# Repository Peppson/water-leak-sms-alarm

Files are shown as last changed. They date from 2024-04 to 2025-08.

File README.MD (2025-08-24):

# water-leak-sms-alarm   
A small battery-powered device that detects water leakage and sends an SMS alert.  
&nbsp;
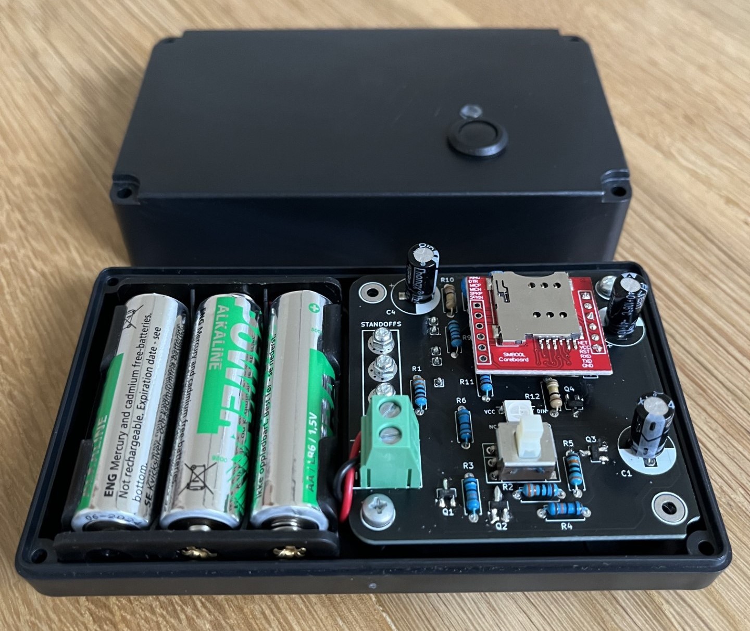
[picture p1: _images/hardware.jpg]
Hardware


&nbsp; 
## Features
- Completely `off` until water *(or anything conductive)* closes the circuit between two of its legs,  
thereby latching on the "soft latching power circuit".  
Which can later be turned off again by the microcontroller.

- Latches `on` by either water detection or by pressing the test button.

- Sends an SMS alert if water is detected.

- Sends SMS diagnostics if the test button is pressed.

- Built with an ESP32 and PlatformIO, in C++.

&nbsp; 
## Schematic and PCB
KiCad files can be found here: 
[📂 _KiCad/](./_KiCad/)  
More images in: 
[📂 _images/](./_images/)
<details>
    <summary>
        Parts used
    </summary>   

- ESP32 D1 Mini Node MCU 
- SIM800L module with external antenna  
- 3.3V LDO: MCP1700-3302E (250mA)
- LED: WS2812B  
- P-channel mos: NTR4101PT1G 
- N-channel mos: PMV16XNR  
- Cap 470uF: Electrolytic  
- Cap 22uF: Electrolytic
- Cap 1uF: Ceramic  
- Cap 100nF: Ceramic
- Switch: Momentary DPST  
- Conductive legs in copper/brass  
</details>

<details>
    <summary>
        PCB
    </summary>   

> Uses mostly through-hole components for easier soldering.  
> ESP32 is mounted on the bottom side of the PCB.

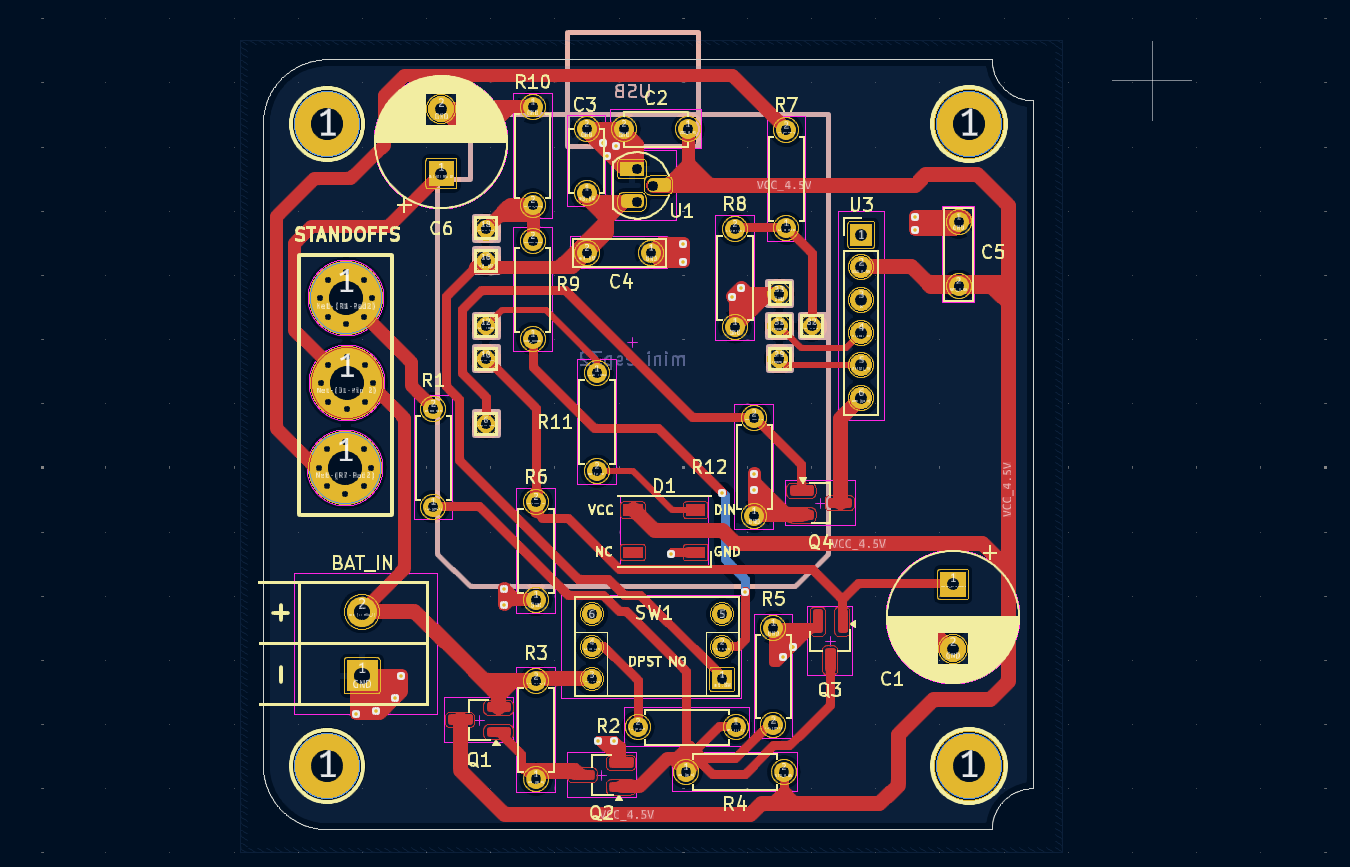
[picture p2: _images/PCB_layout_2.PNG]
PCB

&nbsp;
</details>

### Schematic
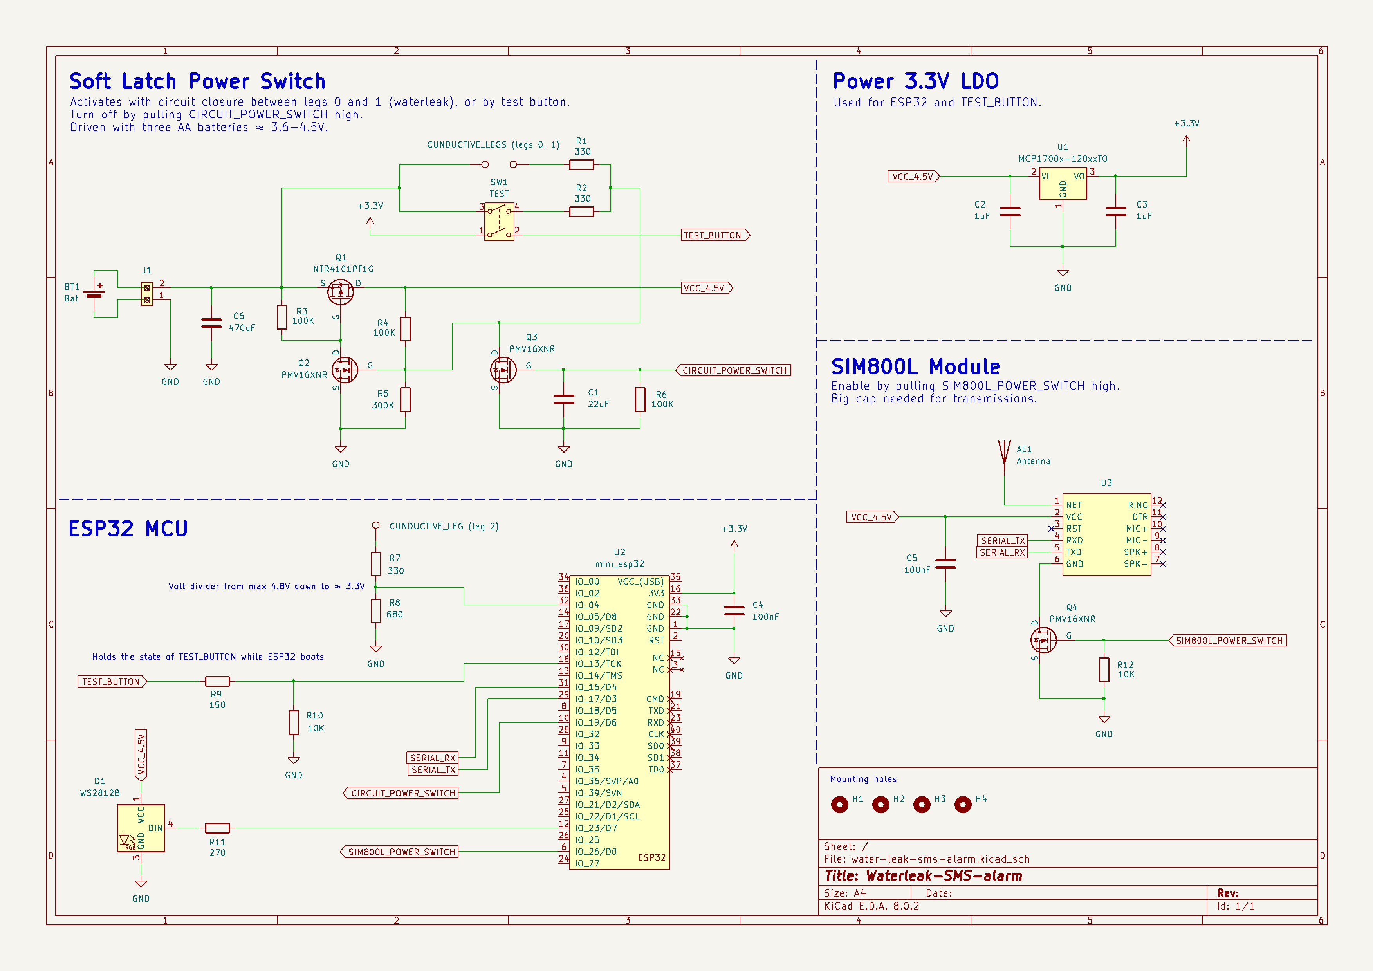
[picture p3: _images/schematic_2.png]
Schematic


### SMS Example

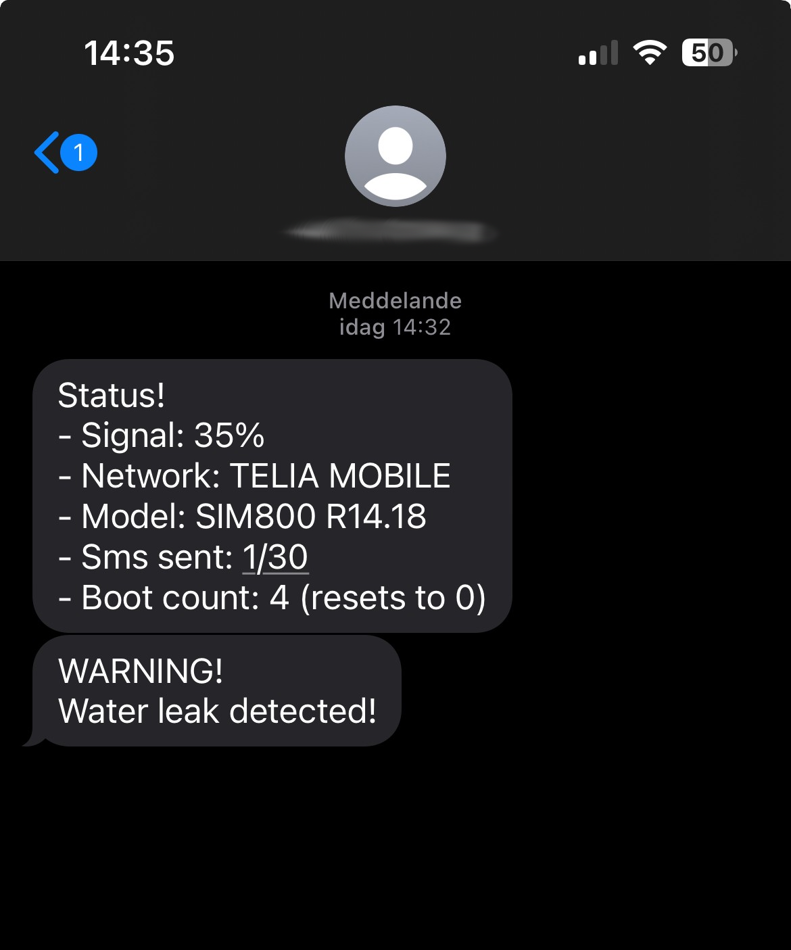
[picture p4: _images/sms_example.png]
SMS Example


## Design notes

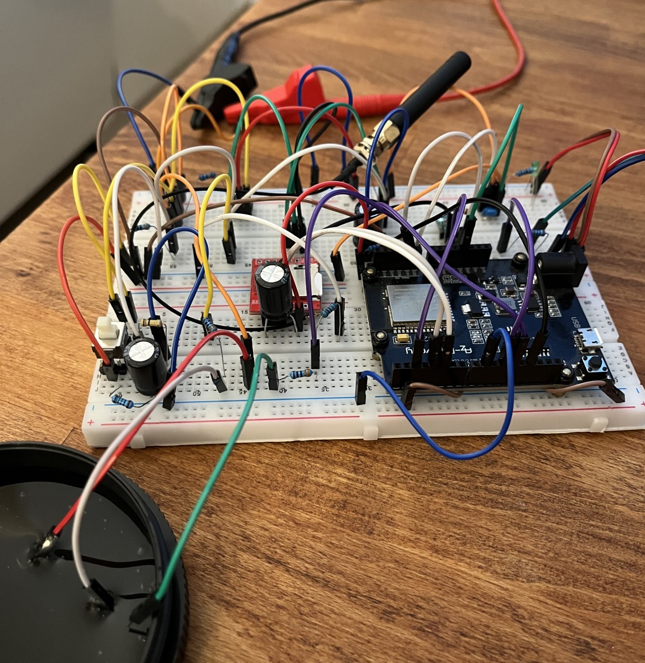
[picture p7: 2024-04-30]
_images/prototype.jpg

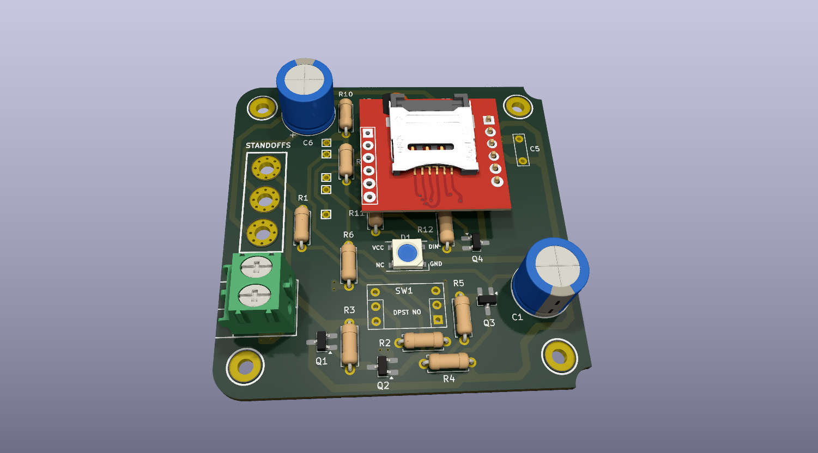
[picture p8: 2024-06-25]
_images/PCB_render_2.PNG

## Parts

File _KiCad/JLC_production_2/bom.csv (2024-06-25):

Designator | Footprint | Quantity | Value | LCSC Part #
BAT_IN | TerminalBlock_Philmore_TB132_1x02_P5.00mm_Horizontal | 1 | Screw_Terminal_01x02
C1 | CP_Radial_D10.0mm_P5.00mm | 1 | 470uF
C2, C3 | C_Disc_D4.7mm_W2.5mm_P5.00mm | 2 | 1uF
C4, C5 | C_Rect_L7.0mm_W2.0mm_P5.00mm | 2 | C_Rect_L7.0mm_W2.0mm_P5.00mm
C6 | CP_Radial_D10.0mm_P5.00mm | 1 | 470
D1 | LED_WS2812B_PLCC4_5.0x5.0mm_P3.2mm | 1 | WS2812B
Q1 | SOT-23_Handsoldering | 1 | NTR4101PT1G
Q2, Q3, Q4 | SOT-23_Handsoldering | 3 | PMV16XNR
R1, R2, R7 | R_Axial_DIN0207_L6.3mm_D2.5mm_P7.62mm_Horizontal | 3 | 330
R10, R12 | R_Axial_DIN0207_L6.3mm_D2.5mm_P7.62mm_Horizontal | 2 | 10K
R11 | R_Axial_DIN0207_L6.3mm_D2.5mm_P7.62mm_Horizontal | 1 | 270
R3, R4, R6 | R_Axial_DIN0207_L6.3mm_D2.5mm_P7.62mm_Horizontal | 3 | 100K
R5 | R_Axial_DIN0207_L6.3mm_D2.5mm_P7.62mm_Horizontal | 1 | 300K
R8 | R_Axial_DIN0207_L6.3mm_D2.5mm_P7.62mm_Horizontal | 1 | 680
R9 | R_Axial_DIN0207_L6.3mm_D2.5mm_P7.62mm_Horizontal | 1 | 150
S1 | MountingHole_2.7mm_M2.5_Pad_Via | 1 | CUNDUCTIVE_LEGS (legs 0, 1)
S2 | MountingHole_2.7mm_M2.5_Pad_Via | 1 | CUNDUCTIVE STANDOFFS (legs 1, 2)
S3 | MountingHole_2.7mm_M2.5_Pad_Via | 1 | CUNDUCTIVE_LEG (leg 2)
SW1 | SW_NKK_G1xJP | 1 | TEST
U1 | TO-92_HandSolder | 1 | MCP1700x-120xxTO
U2 | esp32-wemos-d1-mini | 1 | mini_esp32
U3 | PinHeader_1x06_P2.54mm_Vertical | 1 | SIM800L-CORE

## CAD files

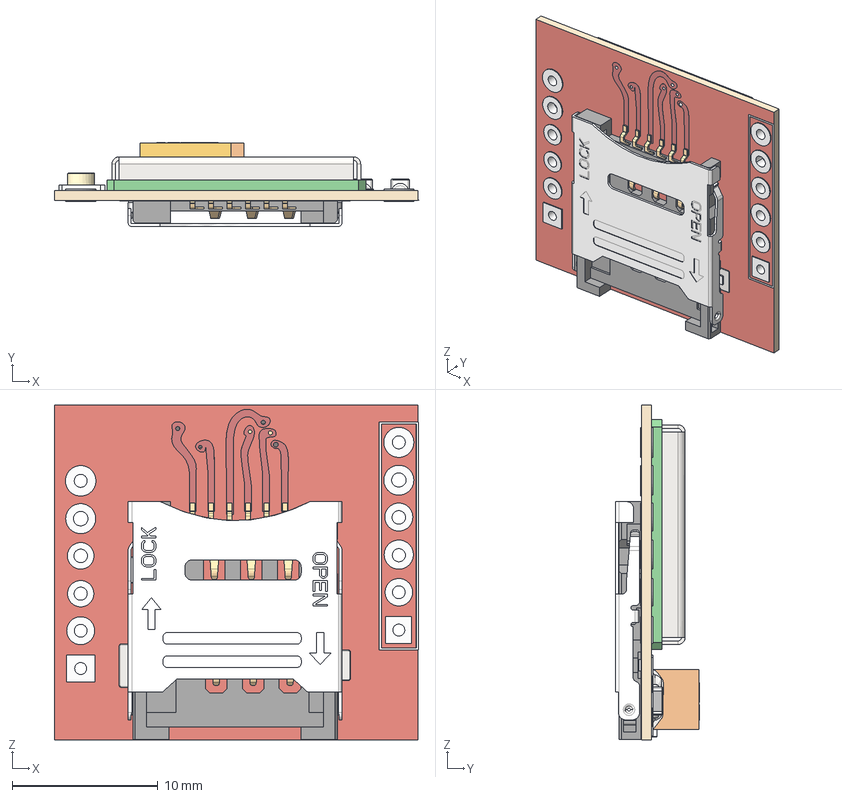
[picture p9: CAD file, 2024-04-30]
_KiCad/SIM800L-Core-Module-KiCad-Footprint-main/SIM800L v10.step
25.0 x 5.77 x 23.0 mm
PCB
Cage
CH03-HB

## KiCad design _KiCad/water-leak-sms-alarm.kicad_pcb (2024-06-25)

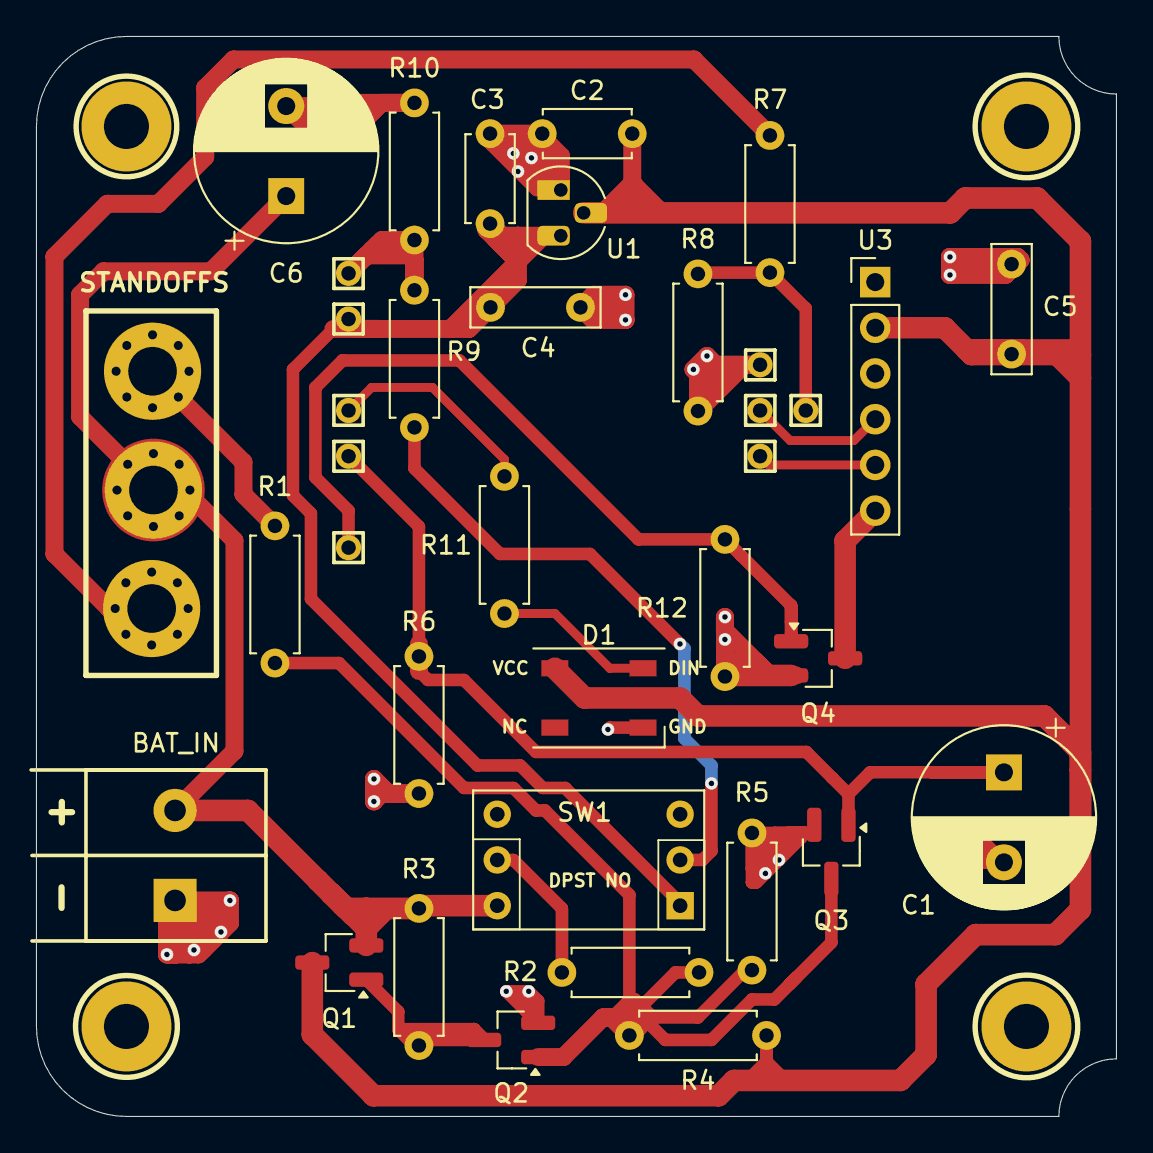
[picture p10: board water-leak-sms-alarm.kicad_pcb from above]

Board: 2 copper layers, 60.0 x 60.0 mm, 35 parts (1 on the bottom side), 19 nets.

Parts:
BAT_IN: Screw_Terminal_01x02; TerminalBlock_Philmore_TB132_1x02_P5.00mm_Horizontal
C1: 470uF; CP_Radial_D10.0mm_P5.00mm
C2, C3: 1uF; C_Disc_D4.7mm_W2.5mm_P5.00mm
C4, C5: C_Rect_L7.0mm_W2.0mm_P5.00mm
C6: 470; CP_Radial_D10.0mm_P5.00mm
D1: WS2812B; LED_WS2812B_PLCC4_5.0x5.0mm_P3.2mm
H1, H2, H3, H4: MountingHole; MountingHole_2.5mm_Pad
Q1: NTR4101PT1G; SOT-23_Handsoldering
Q2, Q3, Q4: PMV16XNR; SOT-23_Handsoldering
R1, R2, R7: 330; R_Axial_DIN0207_L6.3mm_D2.5mm_P7.62mm_Horizontal
R3, R4, R6: 100K; R_Axial_DIN0207_L6.3mm_D2.5mm_P7.62mm_Horizontal
R5: 300K; R_Axial_DIN0207_L6.3mm_D2.5mm_P7.62mm_Horizontal
R8: 680; R_Axial_DIN0207_L6.3mm_D2.5mm_P7.62mm_Horizontal
R9: 150; R_Axial_DIN0207_L6.3mm_D2.5mm_P7.62mm_Horizontal
R10, R12: 10K; R_Axial_DIN0207_L6.3mm_D2.5mm_P7.62mm_Horizontal
R11: 270; R_Axial_DIN0207_L6.3mm_D2.5mm_P7.62mm_Horizontal
S1: CUNDUCTIVE_LEGS (legs 0, 1); MountingHole_2.7mm_M2.5_Pad_Via
S2: CUNDUCTIVE STANDOFFS (legs 1, 2); MountingHole_2.7mm_M2.5_Pad_Via
S3: CUNDUCTIVE_LEG (leg 2); MountingHole_2.7mm_M2.5_Pad_Via
SW1: TEST; SW_NKK_G1xJP
U1: MCP1700x-120xxTO; TO-92_HandSolder
U2: mini_esp32; esp32-wemos-d1-mini
U3: SIM800L-CORE; PinHeader_1x06_P2.54mm_Vertical

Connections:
+3.3V: C3.1, C4.2, SW1.1, U1.3 (VO), U2.16 (3V3)
CIRCUIT_POWER_SWITCH: C1.1, Q3.1 (D), R6.2, U2.10 (IO_19/D6)
GND: BAT_IN.1, C1.2, C2.2, C3.2, C4.1, C5.1, C6.2, D1.3 (GND), Q2.2 (G), Q3.2 (G), Q4.2 (G), R5.1, R6.1, R8.1, R10.1, R12.1, U1.1 (GND), U2.33 (GND)
unnamed: D1.4 (DIN), R11.2
unnamed: BAT_IN.2, C6.1, Q1.2 (G), R3.2, S1.1, SW1.3
unnamed: Q1.1 (D), Q2.3 (S), R3.1
unnamed: Q2.1 (D), Q3.3 (S), R1.1, R2.1, R4.1, R5.2
unnamed: Q4.3 (S), U3.6 (GND)
unnamed: R1.2, S2.1
unnamed: R2.2, SW1.4
unnamed: R7.2, S3.1
unnamed: R7.1, R8.2, U2.32 (IO_04)
unnamed: R9.2, R10.2, U2.18 (IO_13/TCK)
unnamed: R11.1, U2.12 (IO_23/D7)
SERIAL_RX: U2.29 (IO_17/D3), U3.5 (TXD)
SERIAL_TX: U2.31 (IO_16/D4), U3.4 (RXD)
SIM800L_POWER_SWITCH: Q4.1 (D), R12.2, U2.6 (IO_26/D0)
TEST_BUTTON: R9.1, SW1.2
VCC_4.5V: C2.1, C5.2, D1.1 (VCC), Q1.3 (S), R4.2, U1.2 (VI), U3.2 (VCC)

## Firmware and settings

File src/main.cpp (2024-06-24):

#include "config.h"
#include "core/gsm_module.h"
#include "core/hardware.h"
#include "core/memory.h"
#include "utility.h"

using namespace hardware;
Memory memory;
GsmModule sms;

// Main
void setup() {
    begin_hardware(&memory, &sms);

    // Diagnostic test button
    if (is_test_button_pressed()) {
        sms.send_message(SMSType::Diagnostic);
        system_shutdown();
    }

    // Did we wake up from deepsleep? (reboots itself after deepsleep)
    if (woke_up_from_deepsleep()) {
        system_shutdown();
    }

    // Normal boot
    memory.increment_eeprom_count(MemAddr::BootCount, 1, false);  

    if (is_water_leak_detected()) {
        sms.send_message(SMSType::Alert);
        deepsleep(DEEPSLEEP_DURATION_LONG);  // Deepsleep to prevent retriggering
        /*OFF*/
    } else {
        deepsleep(DEEPSLEEP_DURATION_SHORT);  // False positive
        /*OFF*/
    }

    // Debug/development
    #if USB_SERIAL_ENABLED && DEBUG_LOOP_ENABLED
        util::debug_loop(memory, sms);
    #endif
}


void loop() {
    system_shutdown(); // Should never get here
} 

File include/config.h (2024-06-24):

#pragma once
#include <Arduino.h>
#include <stdbool.h>
#include <stdexcept>
#include <stdio.h>
#include <string>
#include <EEPROM.h>


// Dev
#define SEND_SMS_ENABLED 1                                          // SMS toggle 
#define USB_SERIAL_ENABLED 0                                        // USB serial connection toggle
#define DEBUG_LOOP_ENABLED 0                                        // Enter debug loop
#define DEBUG_LOOP_PING 0                                           // Serial print (".") while in debug_loop, sometimes helps with connection     
#define RESET_ALL 0                                                 // Resets all counters and await new code upload   

// Setup
constexpr const char* SMS_ALERT_ROW_0 = "WARNING!";                 // Alert sms first row
constexpr const char* SMS_ALERT_ROW_1 = "Water leak detected!";     // Alert sms second row
constexpr const char* SMS_DIAGNOSTIC_ROW_0 = "Status!";             // Diagnostic sms first row
constexpr uint32_t CONNECTION_TIMEOUT = 45*1000;                    // Wait for GSM network connection (mS)
constexpr uint32_t DEEPSLEEP_DURATION_LONG = 2*60*60;               // Deepsleep after waterleak is detected (S)
constexpr uint32_t DEEPSLEEP_DURATION_SHORT = 10;                   // Deepsleep after false positive (S)
constexpr uint16_t SERIAL_RESPONSE_TIMEOUT = 75;                    // Wait for serial response from SIM800L (mS)
constexpr uint16_t MAX_SMS_UNTILL_EMPTY_SIMCARD = 50;               // How many sms can we send in total? (money/sms cost)
constexpr uint64_t DEEPSLEEP_uS_TO_S_FACTOR = 1000000;              // Factor

// Physical I/O
#define PIN_CIRCUIT_POWER_SWITCH 19                                 // Pull HIGH to turn off ALL power (latching circuit)
#define PIN_SIM800L_POWER_SWITCH 26                                 // Turn on/off power to the SIM800L module 
#define PIN_TEST_BUTTON 13                                          // Input push button
#define PIN_WATERLEAK_DETECT 4                                      // Input (third conductive leg) to detect water leakage
#define PIN_LED 23                                                  // Datapin WS2812B led (SPI MOSI)
#define PIN_SIM800L_RX 17                                           // ESP32 hardware serial 2 RX
#define PIN_SIM800L_TX 16                                           // ESP32 hardware serial 2 TX

// Print toggle
#if USB_SERIAL_ENABLED
    #define log(...) Serial.printf(__VA_ARGS__)
    #define STOP log("\n-----  Stop right there criminal scum!  ----- \n"); while (1) { delay(1); }
#else
    #define log(...)
    #define STOP
#endif

// Enums
enum class SMSType : uint8_t {
    Alert,
    Diagnostic,
    None
};

enum class Color : uint8_t {
    Orange,
    Green,
    Blue,
    Red,
    Off
};

enum MemAddr : int {
    BootCount,
    SmsSent,
    NumOfMemAddr  // Num of items. Well, it only grew to two
};

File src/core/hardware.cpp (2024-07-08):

#include "core/hardware.h"
#include "utility.h"
#include <HardwareSerial.h>

namespace hardware {
    
static NeoPixelBus<NeoGrbFeature, NeoWs2812xMethod> pixel(1, PIN_LED); // Led
static Memory* _memory_ptr;
static GsmModule* _sms_ptr;


void IRAM_ATTR begin_hardware(Memory* memory, GsmModule* sms) {
    // Whole circuit power switch
    pinMode(PIN_CIRCUIT_POWER_SWITCH, OUTPUT);
    digitalWrite(PIN_CIRCUIT_POWER_SWITCH, LOW);

    // SIM800L power switch
    pinMode(PIN_SIM800L_POWER_SWITCH, OUTPUT);
    digitalWrite(PIN_SIM800L_POWER_SWITCH, LOW);

    pinMode(PIN_TEST_BUTTON, INPUT_PULLDOWN);

    // Memory, Serial and Led
    memory->begin(); 
    begin_USB_serial();
    pixel.Begin();    

    // Store pointers
    _memory_ptr = memory;
    _sms_ptr = sms;

    #if RESET_ALL
        _memory_ptr->reset_eeprom_count(MemAddr::BootCount); 
        _memory_ptr->reset_eeprom_count(MemAddr::SmsSent);
        #if USB_SERIAL_ENABLED
            log("\n\n---- Reset all counters ----\n     Awaiting upload...\n");
        #else 
            Serial.begin(115200);
            while (!Serial) { }
            Serial.printf("\n\n---- Reset all counters ----\n     Awaiting upload...\n");
        #endif
        while (1) { }
    #endif
}


void begin_USB_serial() {
    #if USB_SERIAL_ENABLED 
        Serial.begin(115200);
        while (!Serial) { delay(1); }

        // Print
        constexpr const char* emote = "\xF0\x9F\x98\x8E\xF0\x9F\x98\x8E\xF0\x9F\x98\x8E";
        log("\n\n\n\n");
        log("---- Initializing ---- %s \n", emote);
        log("---- %i Phone number(s)\n", GsmModule::NUM_OF_PHONES_TO_SMS);
        log("---- SEND_SMS_ENABLED = %s\n", SEND_SMS_ENABLED ? "true" : "false");
        util::ESP32_print_wakeup_reason();
    #endif
}


bool is_test_button_pressed() {
    bool pressed = digitalRead(PIN_TEST_BUTTON);

    if (pressed) { log("Test button pressed!\n"); }
    return pressed;
}


bool is_water_leak_detected() {
    pinMode(PIN_WATERLEAK_DETECT, INPUT_PULLDOWN);
    constexpr uint8_t times = 25;
    uint32_t value = 0;
    
    // Get average ADC reading
    for (uint8_t i = 0; i < times; i++) {
        value += analogRead(PIN_WATERLEAK_DETECT);
        delay(1);
    }

    pinMode(PIN_WATERLEAK_DETECT, OUTPUT);
    return (value / times > 5);
}


bool IRAM_ATTR woke_up_from_deepsleep() {
    esp_sleep_wakeup_cause_t wakeup_reason;
    wakeup_reason = esp_sleep_get_wakeup_cause();

    return (wakeup_reason == ESP_SLEEP_WAKEUP_TIMER);
}


void deepsleep(const uint32_t& sleep_duration_seconds) {
    // Skip the normal deepsleep while debugging
    #if USB_SERIAL_ENABLED && DEBUG_LOOP_ENABLED
        return;
    #endif
    
    peripherals_shutdown();
    log("Deepsleep: %s\n", (sleep_duration_seconds < 60) ? "Short" : "Long");

    // Set wakeup sources: Timer and TEST_BUTTON
    esp_sleep_enable_timer_wakeup(sleep_duration_seconds * DEEPSLEEP_uS_TO_S_FACTOR);
    esp_sleep_enable_ext0_wakeup(GPIO_NUM_13, 1);
    static_assert(PIN_TEST_BUTTON == 13, "TEST_BUTTON GPIO changed!");

    // ZzzzZZZzzZZZz
    delay(1000); // Needed to prevent bootlooping
    esp_deep_sleep_start();
    /*reboot*/
}


void peripherals_shutdown() {
    // GsmModule
    if (_sms_ptr) { 
        _sms_ptr->flush_buffers();
        _sms_ptr->power_off(); 
    }
    // EEPROM memory
    if (_memory_ptr) { 
        _memory_ptr->end(); 
    }
    // Led 
    led_end();
}


void system_shutdown() {
    peripherals_shutdown();

    // Circuit power latch OFF
    log("Power OFF!\n");
    digitalWrite(PIN_CIRCUIT_POWER_SWITCH, HIGH);  
    while (1) { }
    /* OFF */
}


void set_led_color(SMSType sms_type) {
    switch (sms_type) {
        case SMSType::Alert:
            hardware::led_color(Color::Orange); 
            break;
        case SMSType::Diagnostic:
            hardware::led_color(Color::Blue); 
            break;
        default:
            break;
    }
    delay(1);
}


void led_color(Color color) {
    const int led_index = 0; // Only 1 led in total
    
    // Set led color (color can be "Off")
    RgbColor RGB = map_color_to_RGB(color);
    pixel.SetPixelColor(led_index, RGB);
    pixel.Show();
}


void led_blink(size_t times, Color color, uint delay_ms) {
    for (size_t i = 0; i < times; i++) {
        led_color(color);       // On
        delay(delay_ms);
        led_color(Color::Off);  // Off
        delay(delay_ms);
    }
}


void led_end() {
    led_color(Color::Off);
    delay(3); // Needed
    pixel.~NeoPixelBus();
}


RgbColor map_color_to_RGB(Color color) {
    switch (color) {
        case Color::Orange:
            return RgbColor(175, 35, 0);
        case Color::Green:
            return RgbColor(0, 155, 0);
        case Color::Blue:
            return RgbColor(0, 0, 175);
        case Color::Red:
            return RgbColor(155, 0, 0);
        case Color::Off:
            return RgbColor(0, 0, 0);
        default:
            return RgbColor(0, 0, 0);
    }
}
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
